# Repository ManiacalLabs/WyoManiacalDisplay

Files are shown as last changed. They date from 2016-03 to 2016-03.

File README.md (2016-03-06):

# WyoManiacalDisplay

After we unveiled [Colossus](maniacallabs.com/Colossus) back in September, our good friends at [WyoLum](http://WyoLum.com) challenged us to make something awesome with their [TiM LED panels](http://www.seeedstudio.com/depot/TiM-p-1516.html) and have it ready for the [NoVA Maker Faire](http://makerfairenova.com/) in Reston, VA on Marth 13th.

Many, many late nights  of coding, soldering, 3D printing, and fabricating later...

<a href="http://www.youtube.com/watch?feature=player_embedded&v=9yjcHflWVkI
" target="_blank">WyoManiacal Display</a>

CLICK THUMBNAIL FOR YOUTUBE VIDEO

Here's the specs:

- 24 WyoLum TiM WS2812 Panels (in a 6 x 4 grid)
- 64 x 48 Total Resolution - 3072 Pixels!
- 3 Teensy 3.2's running modified [AllPixel](maniacallabs.com/AllPixel) firmware
- Custom adapter PCBs with 74HCT245 buffer
- 104A @ 5V Max power draw
- Up to 60fps
- Controlled by [BiblioPixel](maniacallabs.com/BiblioPixel)
- 175 3D printed components totaling 15 separate designs
- [Acrylite 7C056](https://www.acrylite-shop.com/US/us/extruded-f0p5v3qaql1/acrylite-extruded-ff-grey-7c056-gt-ckhtgnt8efh~p.html) 8% transmission black acrylic front cover
- Frame constructed from 3/4" MDF
- 46" x 36" x 6" Total Dimensions

The display is actually divided into three separate sub-displays, each with 8 TiM panels, a 40A@5V power supply, and a Teensy 3.2 controller. These three sections are capable of acting independently, but are coordinated via BiblioPixel's [multiple driver support](https://github.com/ManiacalLabs/BiblioPixel/wiki/Multiple-Driver-Support).

In order to achieve the highest possible framerate, we had to ditch the usual method of treating the display as one long strand of pixels. If we did it that way, it would take around 100ms just to update all the pixels once (WS2812 LEDs use a slow 800khz data rate) and that would mean a max frame-rate of 10fps. No good. This is where the Teensy and FastLED comes in. With some brilliant code from the FastLED guys, the Teensy can control WS2812 LEDs on up to 16 parallel channels simultaneously using DMA (Direct Memory Access). This allows almost no CPU load to push data to 1024 pixels (16 channels of 64 pixels each) in under 4ms. This is what the adapter PCB is for... it breaks out the 16 outputs from the Teensy, through the 74HCT245 buffer (which brings it from 3.3V to 5V logic), and through some impedance matching resistors.  This is done three times over (once for each sub-display) threaded in parallel (a feature built into BiblioPixel) allowing for a total update time of under 6ms (there's a little overhead for the USB). MUCH better than 100ms! This allows a theoretical frame-rate of over 150fps, but in practice it takes longer to generate the frame than it does to push it, so 60fps is more reasonable to expect.

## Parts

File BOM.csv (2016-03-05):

Qty | Part | Source
24 | WyoLum TiM | http://www.seeedstudio.com/depot/TiM-p-1516.html
3 | Teensy 3.2 | https://www.pjrc.com/store/teensy32.html
6 | 74HCT245N,652 (Control adapter level buffer) | http://www.mouser.com/ProductDetail/NXP/74HCT245N652/
48 | 330 ohm 1/8w resistor (control adapter) | Generic
6 | 1uF Cap (control adapter) | Generic
3 | Adapter PCB | https://oshpark.com/shared_projects/5UyRTd8T
3 | Meanwell LRS-200-5 | http://www.mouser.com/ProductDetail/Mean-Well/LRS-200-5/
4 | 0.5"x0.5"x96" Aluminum C-Channel | http://www.homedepot.com/p/Everbilt-1-2-in-W-x-1-2-in-H-x-96-in-L-Aluminum-C-Channel-with-1-16-in-Thick-802657/204273938
1 | USB Coupler | http://www.amazon.com/gp/product/B00V9GOLXG?psc=1&redirect=true&ref_=oh_aui_detailpage_o01_s00
1 | IEC 320 Cord Adapter | http://www.amazon.com/gp/product/B00066HQ50?psc=1&redirect=true&ref_=oh_aui_detailpage_o02_s00
1 | Power Splitter | https://www.amazon.com/gp/product/B000083KIH/ref=oh_aui_detailpage_o06_s01?ie=UTF8&psc=1
1 | USB Hub Power | https://www.amazon.com/gp/product/B00MRFR1XA/ref=oh_aui_detailpage_o09_s00?ie=UTF8&psc=1
1 | USB Hub | https://www.amazon.com/gp/product/B00BWF5U0M/ref=oh_aui_detailpage_o03_s01?ie=UTF8&psc=1
~30 | M3.5x16mm Wood Screws (Mount panel to frame) | https://www.amazon.com/gp/product/B011BNVRD8/ref=oh_aui_detailpage_o03_s00?ie=UTF8&psc=1
~16 | M4-0.7x18mm (Back panel mount) | https://www.amazon.com/gp/product/B00598DTCE/ref=oh_aui_detailpage_o04_s00?ie=UTF8&psc=1
~50 | #8x3/4" Screw (various frame mount) | https://www.amazon.com/gp/product/B000KWKQTS/ref=oh_aui_detailpage_o05_s00?ie=UTF8&psc=1
~16 | Square M4 Nut (BackPanelBracket.stl) | https://www.amazon.com/gp/product/B019XITPK0/ref=oh_aui_detailpage_o05_s01?ie=UTF8&psc=1
~300 | M3-0.5 Nuts | https://www.amazon.com/gp/product/B000NBIH92/ref=oh_aui_detailpage_o04_s00?ie=UTF8&psc=1
~30 | M3x30mm (Connect vert & horiz rails) | https://www.amazon.com/gp/product/B011BNUJPU/ref=oh_aui_detailpage_o04_s00?ie=UTF8&psc=1
~100 | M3x10mm (Most panel connections) | https://www.amazon.com/gp/product/B000NHVPW2/ref=oh_aui_detailpage_o06_s00?ie=UTF8&psc=1
~50 | M3x16mm (Power Supply Mounts) | https://www.amazon.com/gp/product/B000NHXOCG/ref=oh_aui_detailpage_o06_s00?ie=UTF8&psc=1
2 | Frame handles | https://www.amazon.com/gp/product/B00JQYVGEK/ref=oh_aui_detailpage_o07_s00?ie=UTF8&psc=1
1 | 40" x 31" 8% Black Acrylic | https://www.acrylite-shop.com/US/us/extruded-f0p5v3qaql1/acrylite-extruded-ff-grey-7c056-gt-ckhtgnt8efh~p.html

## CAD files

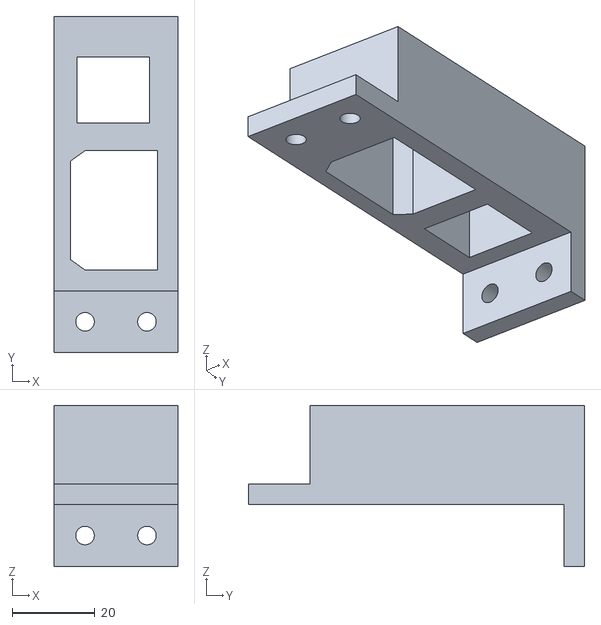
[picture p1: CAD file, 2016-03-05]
Plastics/PowerUSBBracket.stl
30.0 x 81.5 x 39.0

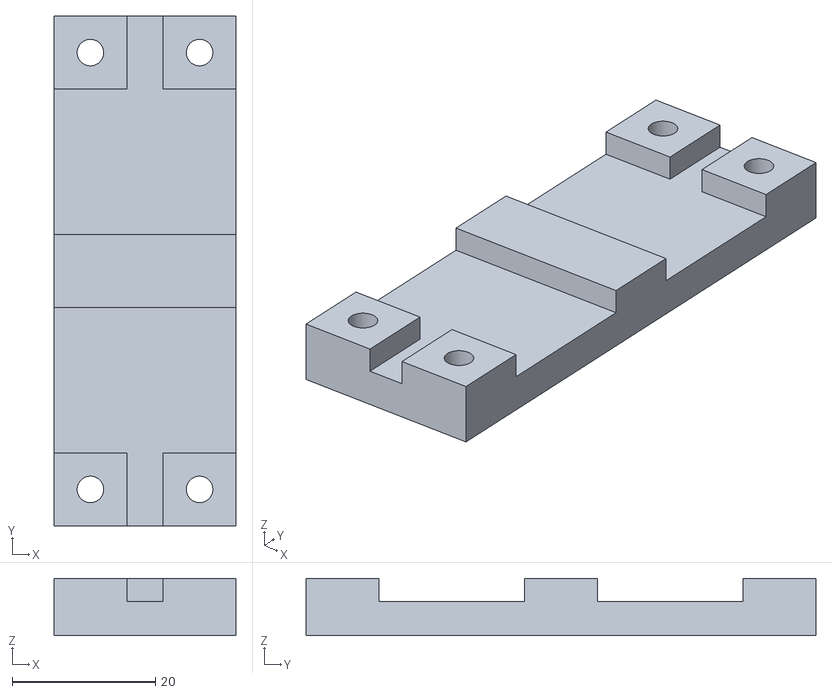
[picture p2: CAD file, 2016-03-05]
Plastics/PanelConnector_2x2.stl
25.4 x 71.1 x 8.00

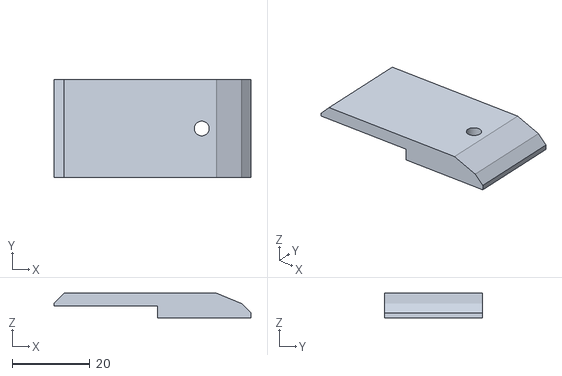
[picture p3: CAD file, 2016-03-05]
Plastics/GlassBracketTB.stl
50.8 x 25.4 x 6.35

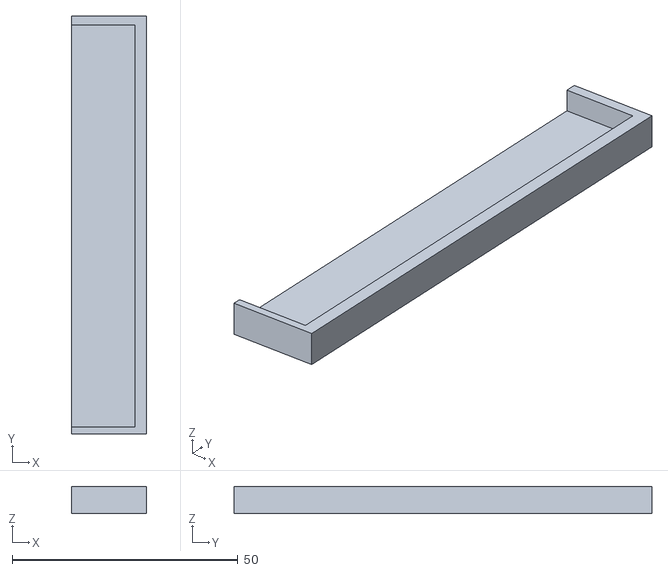
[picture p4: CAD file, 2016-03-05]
Plastics/PowerSupply_TerminalCover.stl
16.5 x 92.5 x 6.00

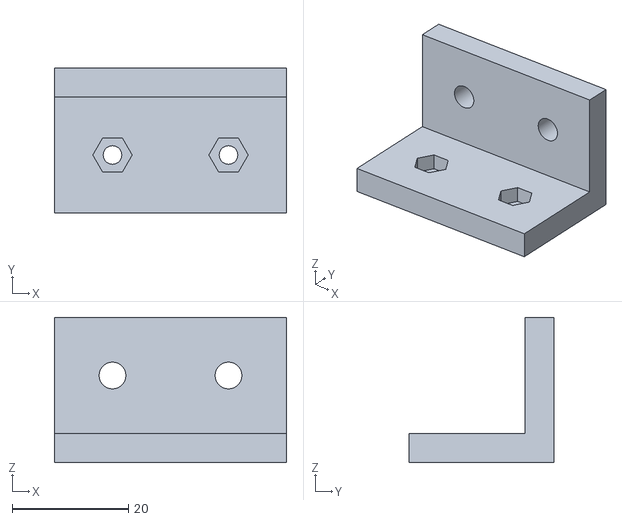
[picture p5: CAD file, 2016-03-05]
Plastics/VerticalFrameSupportBracket.stl
40.0 x 25.0 x 25.0

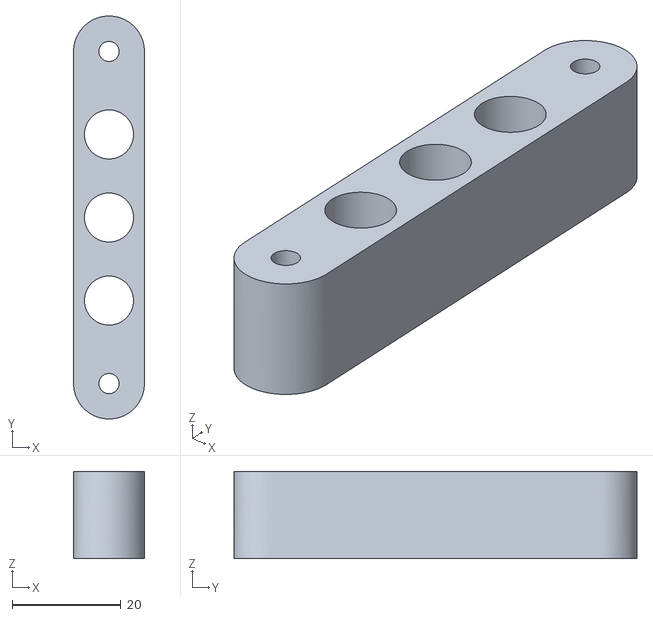
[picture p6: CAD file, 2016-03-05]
Plastics/MetalRail_StandoffDouble.stl
13.0 x 74.0 x 16.0

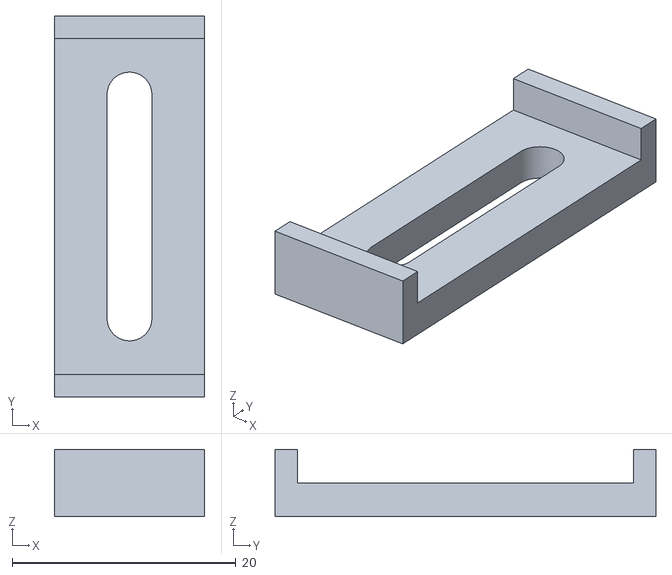
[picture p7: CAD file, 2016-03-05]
Plastics/FrameStandoffs_Double.stl
13.4 x 34.0 x 6.00

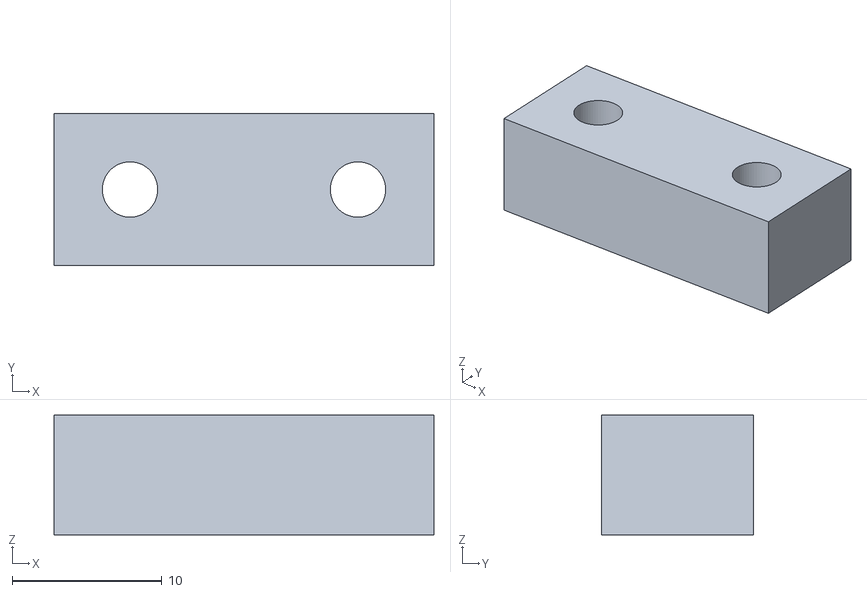
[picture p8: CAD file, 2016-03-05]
Plastics/PanelConnector_1x2Short.stl
25.4 x 10.2 x 8.00

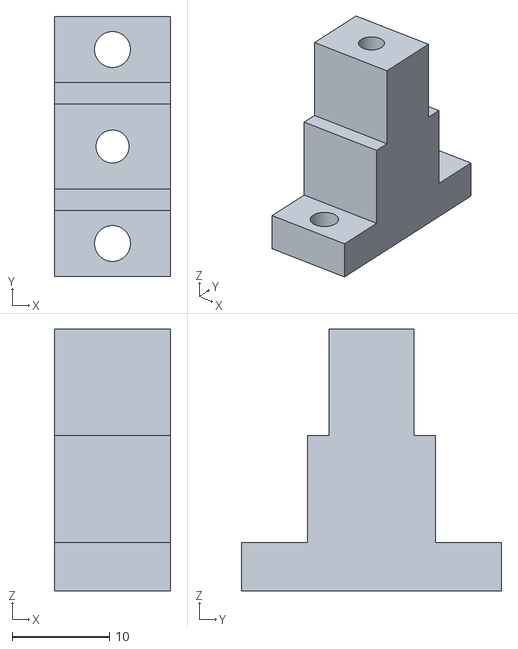
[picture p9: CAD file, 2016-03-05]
Plastics/FrameStandoffs_Tall.stl
12.0 x 26.8 x 27.0

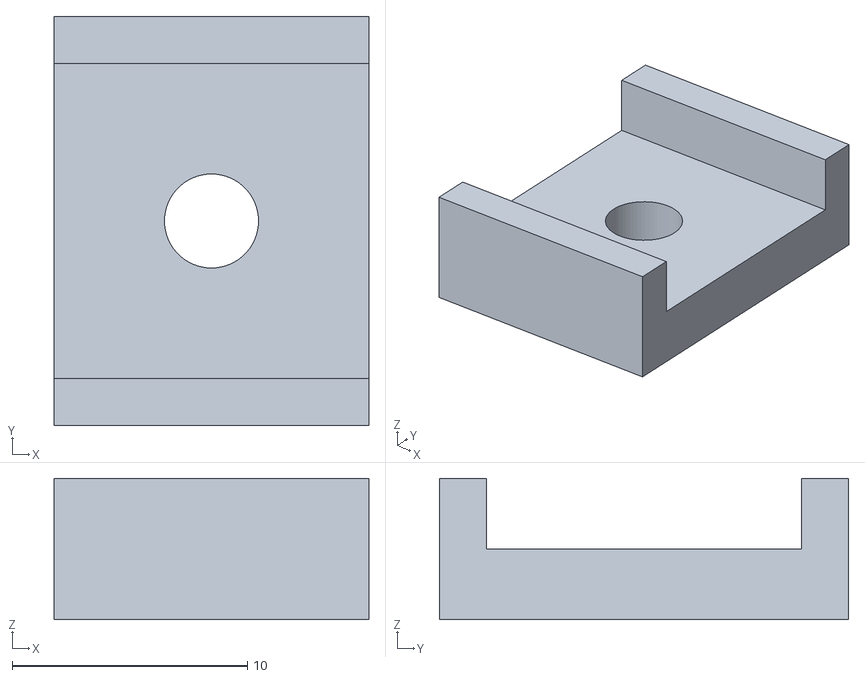
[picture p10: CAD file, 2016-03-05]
Plastics/FrameStandoffs_Single.stl
13.4 x 17.4 x 6.00

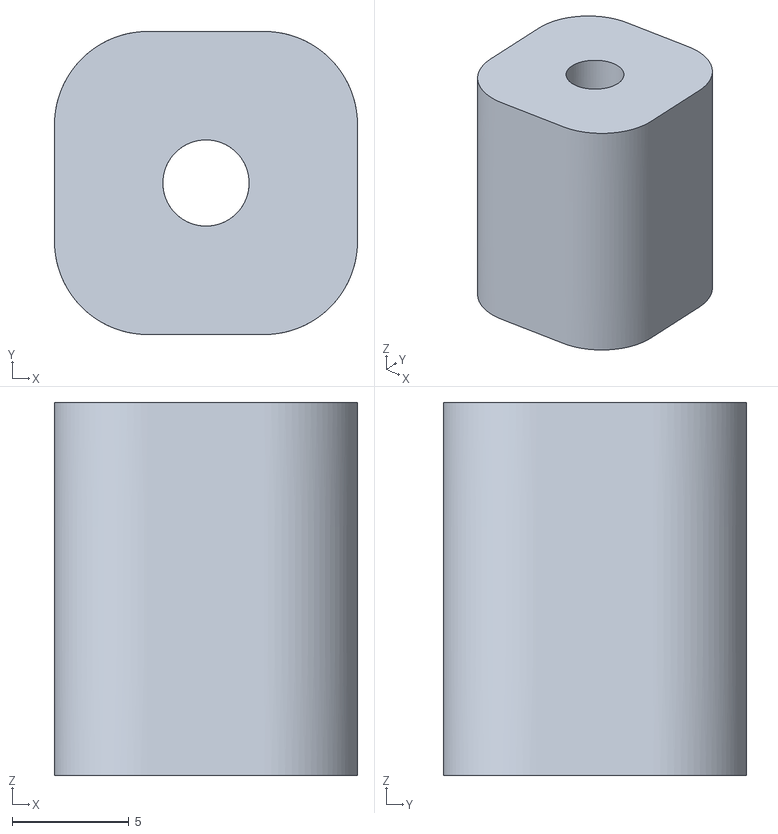
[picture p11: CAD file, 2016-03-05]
Plastics/MetalRail_StandoffSingle.stl
13.0 x 13.0 x 16.0

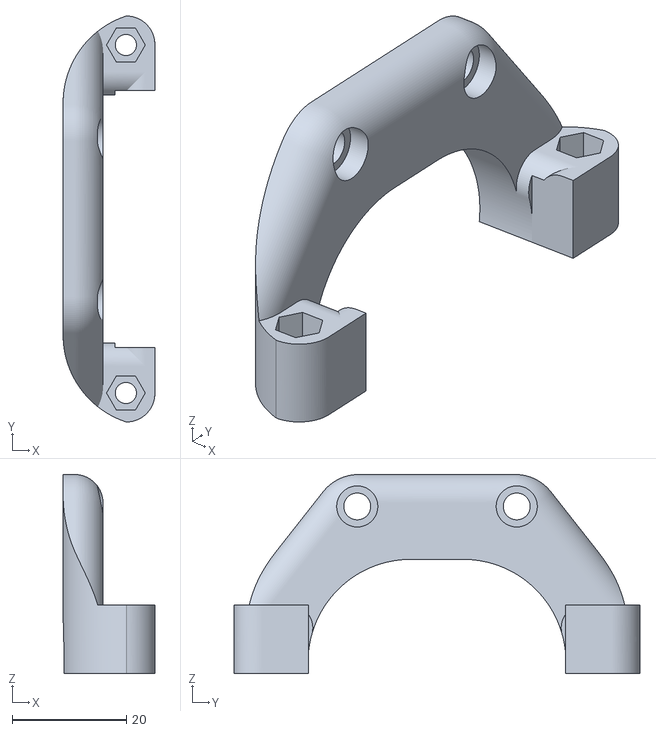
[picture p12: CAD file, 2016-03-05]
Plastics/PowerSupplyMount.stl
16.1 x 71.1 x 34.9

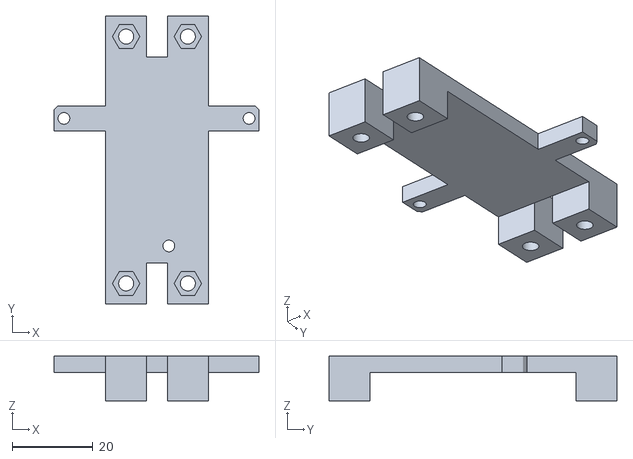
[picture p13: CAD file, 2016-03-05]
Plastics/ControllerBracket.stl
50.6 x 71.1 x 11.0

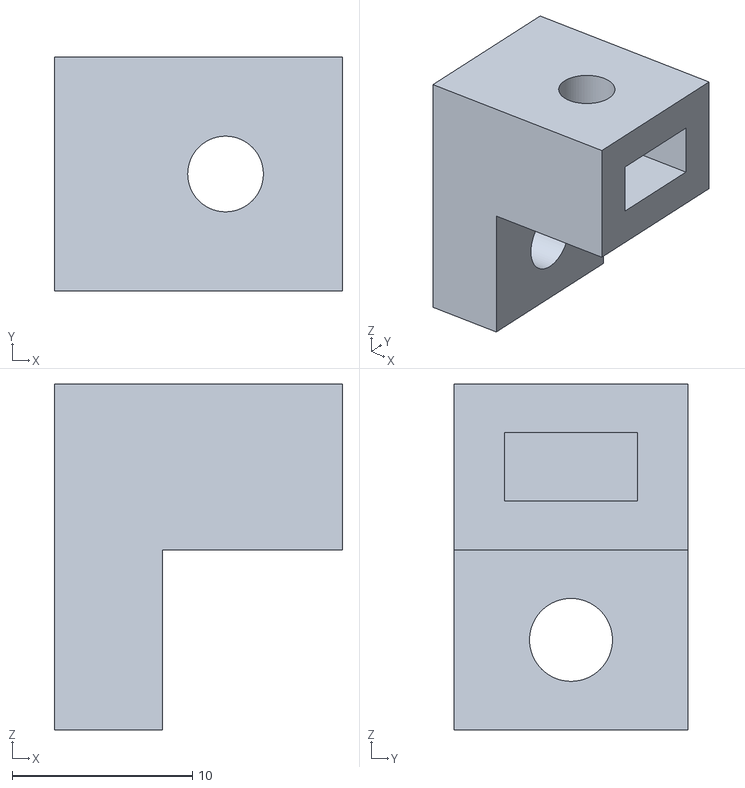
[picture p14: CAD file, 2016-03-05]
Plastics/BackPanelBracket.stl
16.0 x 13.0 x 19.2

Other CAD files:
Plastics/GlassBracketLR.stl
Plastics/PanelConnector_1x2Long.stl
Plastics/MetalRail_Nut.stl

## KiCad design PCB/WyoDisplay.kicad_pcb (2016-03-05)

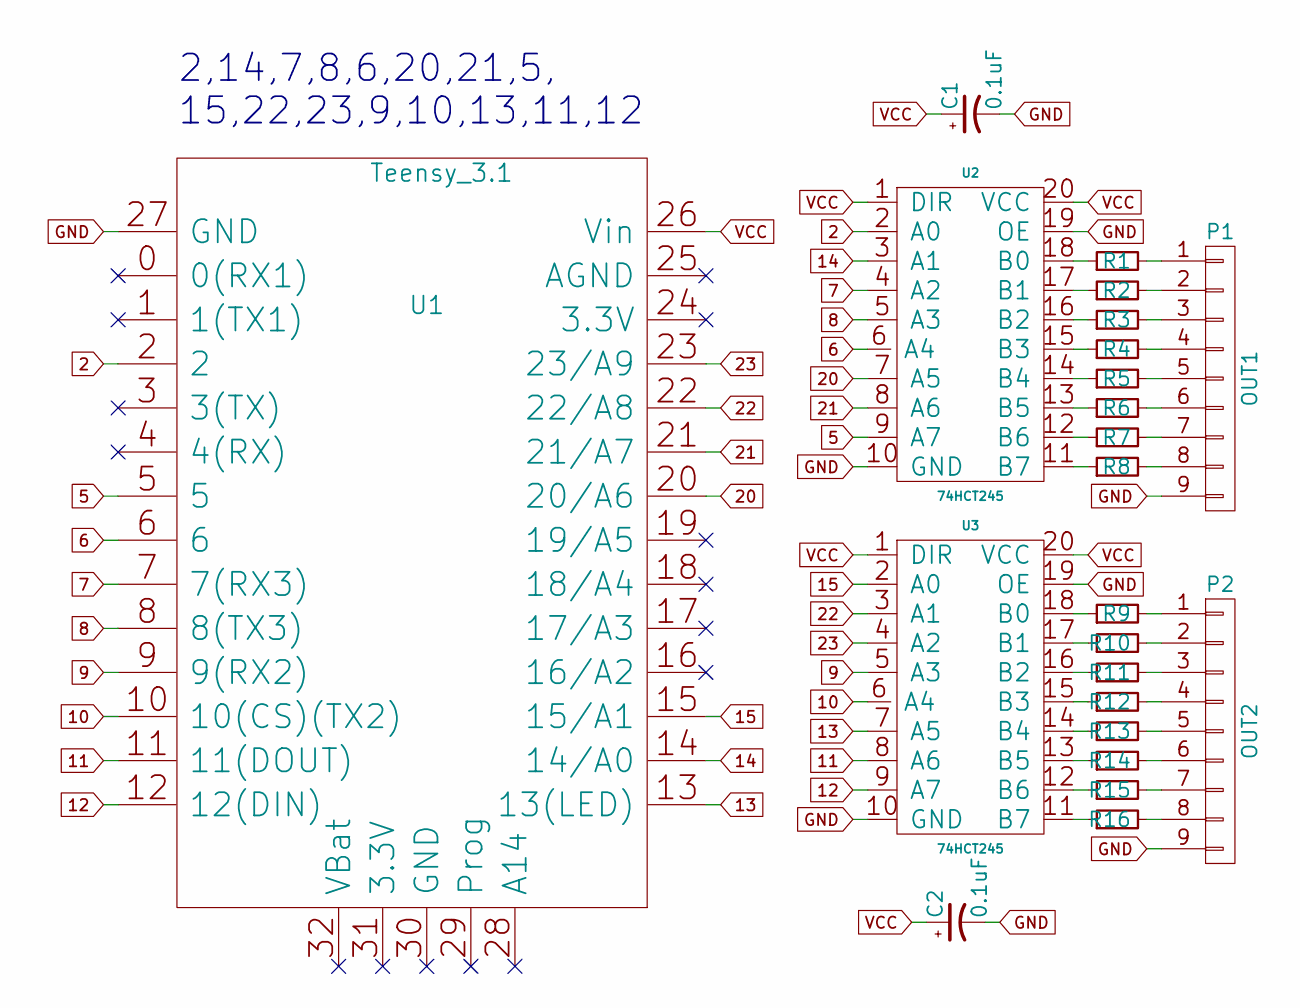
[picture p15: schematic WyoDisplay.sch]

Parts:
C1, C2: 0.1uF; C_Radial_D5_L6_P2.5
P1: OUT1; Pin_Header_Angled_1x09
P2: OUT2; Pin_Header_Angled_1x09
R1, R2, R3, R4, R5, R6, R7, R8, R9, R10, R11, R12, R13, R14, R15, R16: R_Small; R-1-8w
U1: Teensy_3.1; Teensy-3.1
U2, U3: 74HCT245; DIP-20_W7.62mm_LongPads

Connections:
2: U1.2, U2.2 (A0)
5: U1.5, U2.9 (A7)
6: U1.6, U2.6 (A4)
7: U1.7 (7(RX3)), U2.4 (A2)
8: U1.8 (8(TX3)), U2.5 (A3)
9: U1.9 (9(RX2)), U3.5 (A3)
10: U1.10 (10(CS)(TX2)), U3.6 (A4)
11: U1.11 (11(DOUT)), U3.8 (A6)
12: U1.12 (12(DIN)), U3.9 (A7)
13: U1.13 (13(LED)), U3.7 (A5)
14: U1.14 (14/A0), U2.3 (A1)
15: U1.15 (15/A1), U3.2 (A0)
20: U1.20 (20/A6), U2.7 (A5)
21: U1.21 (21/A7), U2.8 (A6)
22: U1.22 (22/A8), U3.3 (A1)
23: U1.23 (23/A9), U3.4 (A2)
GND: C1.2, C2.2, P1.9, P2.9, U1.27 (GND), U2.10 (GND), U2.19 (OE), U3.10 (GND), U3.19 (OE)
unnamed: P1.1, R1.2
unnamed: P1.2, R2.2
unnamed: P1.3, R3.2
unnamed: P1.4, R4.2
unnamed: P1.5, R5.2
unnamed: P1.6, R6.2
unnamed: P1.7, R7.2
unnamed: P1.8, R8.2
unnamed: P2.1, R9.2
unnamed: P2.2, R10.2
unnamed: P2.3, R11.2
unnamed: P2.4, R12.2
unnamed: P2.5, R13.2
unnamed: P2.6, R14.2
unnamed: P2.7, R15.2
unnamed: P2.8, R16.2
unnamed: R1.1, U2.18 (B0)
unnamed: R2.1, U2.17 (B1)
unnamed: R3.1, U2.16 (B2)
unnamed: R4.1, U2.15 (B3)
unnamed: R5.1, U2.14 (B4)
unnamed: R6.1, U2.13 (B5)
unnamed: R7.1, U2.12 (B6)
unnamed: R8.1, U2.11 (B7)
unnamed: R9.1, U3.18 (B0)
unnamed: R10.1, U3.17 (B1)
unnamed: R11.1, U3.16 (B2)
unnamed: R12.1, U3.15 (B3)
unnamed: R13.1, U3.14 (B4)
unnamed: R14.1, U3.13 (B5)
unnamed: R15.1, U3.12 (B6)
unnamed: R16.1, U3.11 (B7)
VCC: C1.1, C2.1, U1.26 (Vin), U2.1 (DIR), U2.20 (VCC), U3.1 (DIR), U3.20 (VCC)

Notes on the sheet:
2,14,7,8,6,20,21,5, 15,22,23,9,10,13,11,12

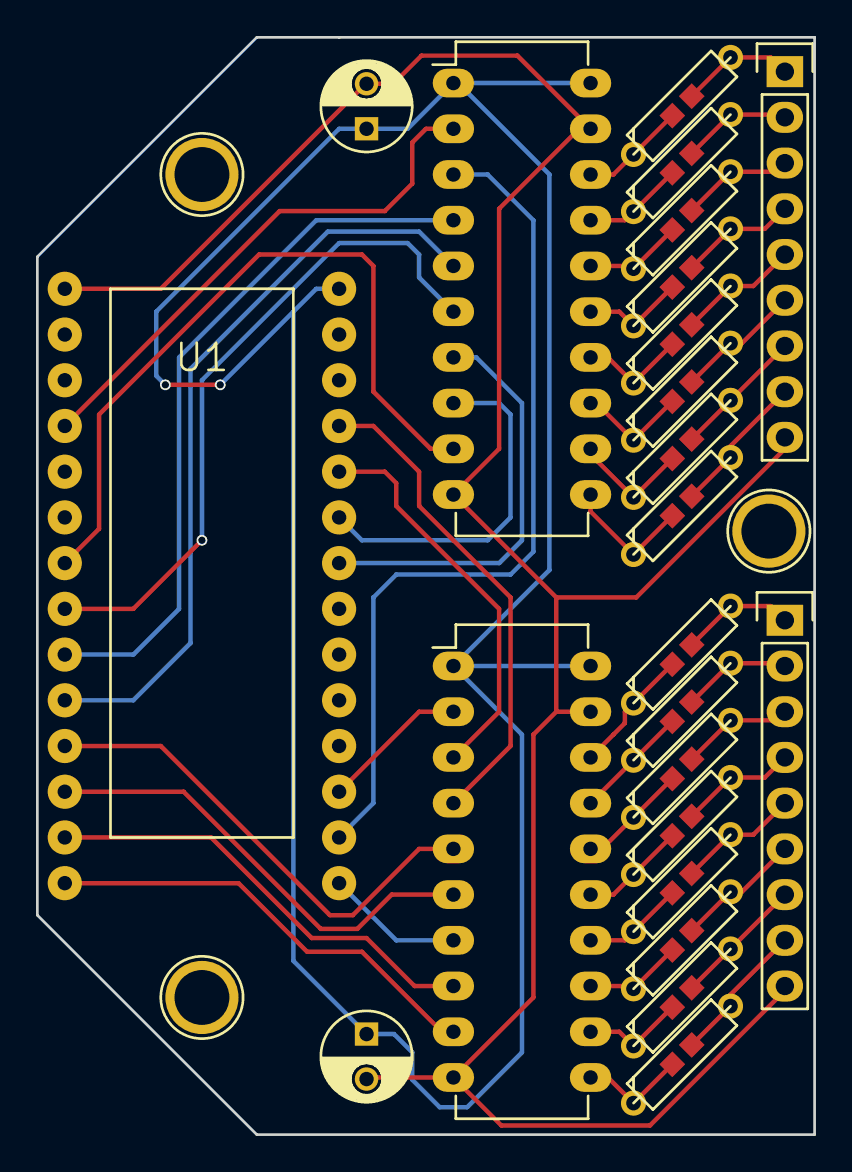
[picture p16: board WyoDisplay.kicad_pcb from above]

Board: 2 copper layers, 43.2 x 61.0 mm, 23 parts (0 on the bottom side), 50 nets.

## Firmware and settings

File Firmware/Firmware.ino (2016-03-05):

#include <SmartMatrix.h>
#include <FastLED.h>
#include <EEPROM.h>
#include "global.h"

#define NUM_LEDS_PER_STRIP 64
#define NUM_STRIPS 16
//WS2811_PORTDC: 2,14,7,8,6,20,21,5,15,22,23,9,10,13,11,12 - 16 way parallel

CRGB * _fastLEDs;

uint16_t numLEDs = NUM_STRIPS * NUM_LEDS_PER_STRIP;
bool errorPixelCount = false;
uint8_t bytesPerPixel = 3;

inline void setupFastLED()
{
	_fastLEDs = (CRGB*)malloc(sizeof(CRGB)*numLEDs);
	memset(_fastLEDs, 0, sizeof(CRGB)*numLEDs);

	LEDS.addLeds<WS2811_PORTDC,NUM_STRIPS>(_fastLEDs, NUM_LEDS_PER_STRIP);

    //FastLED.setDither(DISABLE_DITHER);
	FastLED.clear();
	FastLED.show();
}

void setup()
{
	Serial.begin(1000000);
	Serial.setTimeout(1000);

	if (EEPROM.read(0) != CONFIGCHECK)
	{
		EEPROM.write(0, CONFIGCHECK);
		writeDefaultConfig();
		EEPROM.write(16, 0);
	}

	readConfig();

	setupFastLED();
}

#define EMPTYMAX 100
inline void getData()
{
	static char cmd = 0;
	static uint16_t size = 0;
	static uint16_t count = 0;
	static uint8_t emptyCount = 0;
	static size_t c = 0;
	static uint16_t packSize = numLEDs * bytesPerPixel;

	if (Serial.available())
	{
		cmd = Serial.read();
		size = 0;
		Serial.readBytes((char*)&size, 2);

		if (errorPixelCount)
		{
			Serial.write(RETURN_CODES::ERROR_PIXEL_COUNT);
			Serial.flush();
			delay(100);
			//doReboot();
		}
		else if (cmd == CMDTYPE::PIXEL_DATA)
		{
			count = 0;
			emptyCount = 0;

			if (size == packSize)
			{
				while (count < packSize - 1)
				{
					c = Serial.readBytes(((char*)_fastLEDs) + count, packSize - count);
					if (c == 0)
					{
						emptyCount++;
						if(emptyCount > EMPTYMAX) break;
					}
					else
					{
						emptyCount = 0;
					}

					count += c;
				}
			}

			uint8_t resp = RETURN_CODES::SUCCESS;
			if (count == packSize)
			{
				FastLED.show();
			}
			else
				resp = RETURN_CODES::ERROR_SIZE;

			Serial.write(resp);
		}
		else if(cmd == CMDTYPE::GETID)
		{
			Serial.write(EEPROM.read(16));
		}
		else if(cmd == CMDTYPE::SETID)
		{
			if(size != 1)
			{
				Serial.write(RETURN_CODES::ERROR_SIZE);
			}
			else
			{
				uint8_t id = Serial.read();
				EEPROM.write(16, id);
				Serial.write(RETURN_CODES::SUCCESS);
			}
		}
		else if (cmd == CMDTYPE::SETUP_DATA)
		{
			uint8_t result = RETURN_CODES::SUCCESS;
			config_t temp;

			if (size != sizeof(config_t))
			{
				result = RETURN_CODES::ERROR_SIZE;
			}
			else
			{
				size_t read = Serial.readBytes((char*)&temp, sizeof(config_t));
				if (read != size)
				{
					result = RETURN_CODES::ERROR_SIZE;
				}
				else
				{
					temp.pixelCount = temp.pixelCount / bytesPerPixel;

					if(temp.pixelCount != numLEDs){
						result = RETURN_CODES::ERROR_PIXEL_COUNT;
					}

					if (result == RETURN_CODES::SUCCESS && memcmp(&temp, &config, sizeof(config_t)) != 0)
					{
						memcpy(&config, &temp, sizeof(config_t));

						writeConfig(); //save changes for next reboot

						Serial.write(RETURN_CODES::SUCCESS);
						Serial.flush();
						// delay(100);
						// doReboot(); //Reboot and start over
					}

					//On config we reset the brightness.
					//Otherwise previous brightness values could
					//still be in memory.
					FastLED.setBrightness(255);
					FastLED.setDither(1);
				}
			}

			Serial.write(result);
		}
		else if (cmd == CMDTYPE::BRIGHTNESS)
		{
			uint8_t result = RETURN_CODES::SUCCESS;
			if (size != 1)
				result = RETURN_CODES::ERROR_SIZE;
			else
			{
				uint8_t brightness = 255;
				size_t read = Serial.readBytes((char*)&brightness, 1);
				if (read != size)
					result = RETURN_CODES::ERROR_SIZE;
				else
				{
					FastLED.setBrightness(brightness);
				}
			}

			Serial.write(result);
		}
		else if (cmd == CMDTYPE::GETVER)
		{
			Serial.write(RETURN_CODES::SUCCESS);
			Serial.write(FIRMWARE_VER);
		}
		else
		{
			Serial.write(RETURN_CODES::ERROR_BAD_CMD);
		}


		Serial.flush();
	}

	//Serial.println(freeRam(), DEC);
}

void loop()
{
	getData();
	FastLED.delay(0);
}
